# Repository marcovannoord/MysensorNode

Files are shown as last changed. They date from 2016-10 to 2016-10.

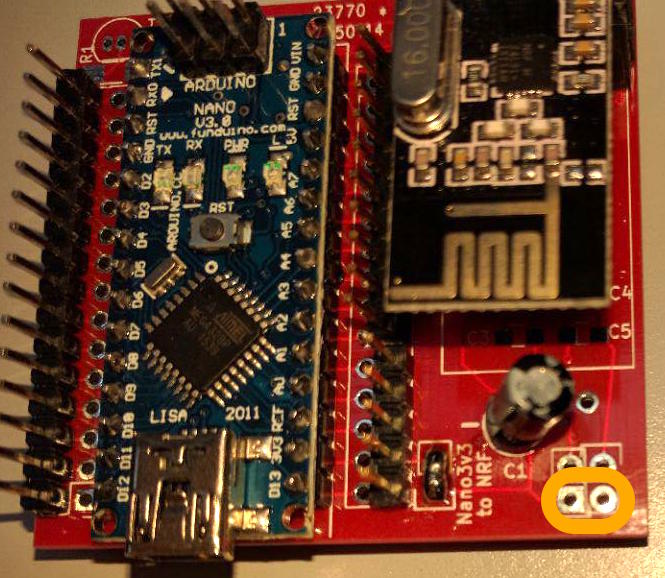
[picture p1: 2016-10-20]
how-to-use-battery-power.jpg

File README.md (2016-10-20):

# MysensorNode
A MySensor node that uses an NTF24l01+ wireless unit to connect to the gateway. We use an Arduino Nano. In this repository you'll find the files i used to design the PCB (KiCad). Unless you're planning to produce your own boards, you don't need those files. 

If you use this board, it means you've connected your Arduino Nano to your NRF24L01+. Also the pins of the Nano are broken out (at the side of the Nano), so you can easily solder wires to them or even use some fancy headers to connect your creations. 

# Why use an arduino Nano instead of the Pro mini? 
Okay, this is a tradeoff between usability and energy-consumption. The pro mini is way better in terms of size and energy-consumption - it doesn't have the usb-controller - but is a lot harder for beginners to program, and using an FTDI-cable might be a bit scary for beginning users. 

If you wanna save energy , just cut the powertraces for the usb-serial chip. If you're feeling fancy, make a header so you can reconnect the usb-serial. Or you can just program it using the ICSP header using a programmer :) 

# Getting started: getting mysensors working
After you made yourself familiar with the mySensors system https://www.mysensors.org , you figured you need a gateway and of course some nodes to which you connect sensors.

## Warning: Install the library from the MySensors.zip i attached in this repo.

1. Solder female headers on the PCB, exactly where the Arduino Nano is supposed to be and also where the NRF24L01+ should connect. This way you can always remove the nano for testing purposes.
2. Connect the two pins next to "Nano3v3 to NRF" to each other, which will supply the wireless chip with some juice.
3. solder a 47uF electrolythic condensator to C1. Make sure that the "-" of the ElCo faces the same side as the "-" on the PCB.
4. Plug in the Arduino Nano (USB connector should be slightly sticking out) and the NRF24L01+(not sticking out).
5. Plug in the USB, and upload the "SerialGateway" sketch from the MySensors arduino library (https://www.mysensors.org/build/serial_gateway). 
6. Make any of the sensors, for example https://www.mysensors.org/build/binary . 
7. Connect the serial gateway to a Controller (i advice https://www.mysensors.org/controller/mynodesnet or Domoticz) and you're ready to receive data! (p.s. there's a controller in the greenhouse @ RDM already available, connect to DoosWifi and connect to Raspberrypiarjen.local )

After powering on your wireless node, it will search for an active controller in the network, which it will ask a unique device id; it will store that internally in its EEPROM. It will be saved even after losing power. Now you can send data to the controller. Using default settings, you can send/receive approximately 200 messages per second.

# FAQ:

Q: i get an error compiling the system can't find MySensors.h

A: in your sketch, change the reference from mysensors.h to MySensor.h (so remove the "s").

# More Info:
See the Wiki <https://github.com/marcovannoord/MysensorNode/wiki>

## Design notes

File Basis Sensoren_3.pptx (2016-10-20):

## Basis Sensoren Week 3

Door: marco van Noord
Email: Nooma@hr.nl

## Vorige keer

- Digitale sensoren
  - Hoe beviel dat?Beter? Minder?
- Meer libraries, minder zelf schrijven, goed of slecht?

## Vandaag

- Arduino als Smart Thing
  - Power consumption
  - Communicatie

## Draadloze communicatie

## Draadloze communicatie

- Wi-Fi
- Xbee
- Infrarood?
- 434MHz (klik-aan-klik-uit)
- GSM/GPRS
- Lora
- Bluetooth
- …

## Beste kiezen

- Range
  - Repeaters mogelijk?
- Energieverbruik (!)
- Kosten
- Formaat
- Benodigde snelheid

## Energieverbruik

- Draadloze communicatie gebruikt “veel”
  - Vaak het duurste
- Wat als de batterijen leeg zijn?
- Wat voor energiebron (groot/klein, duur/goedkoop, speciaal/standaard, etc…)
- Gebruik niets wat je niet nodig hebt

## Gedrag batterijen

- Verder ontladen => lager voltage
- Microcontroller heeft minimum nodig (zie datasheet)
- Te weinig voltage -> rare dingen doen!
  - Beveiliging(brown-out detection)
- Hoger voltage -> meer verbruik

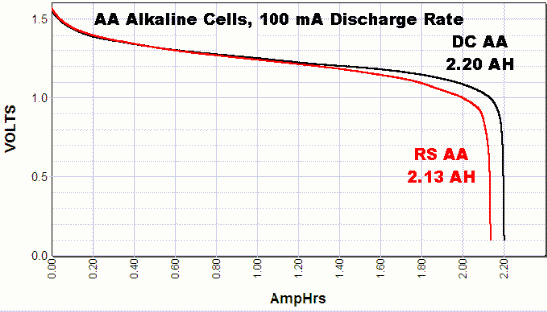
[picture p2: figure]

## Invloed energieverbruik Arduino

- Snelheid (een kloktik kost energie)
  - Dus: veel processing is duur
- Gebruik onboard devices
  - Serieel, SPI, I2C, Interne/externe klok,A/D converter, LED’s
- Voltage regelaars
- Timers
- Interrupts
- Stroom standaard Uno: 47mA

## Design for low-power environments

- Schakel uit wat je niet gebruikt
- Koppel los wat je niet gebruikt
- Debug/statusLED’s nodig in productie?
- Juiste voltage
  - Niet te hoog, niet te lag
- Kloksnelheid aanpassen
- Schakel uit wat je niet continu nodig hebt
- Houd je accuniveau in de gaten
- Slapen

## Sleep

- Sleept zorgt voor lage power-consumption
- Code stopt met draaien!
- Wakker worden: interrupt
  - Timer of extern?

## Stroomgebruik Atmega328p @16MHz

- Arduino: 47mA
- Atmega328P: 36mA
- SLEEP_MODE_IDLE: 15 mA
- SLEEP_MODE_ADC: 6.5 mA
- SLEEP_MODE_PWR_SAVE: 1.62 mA
- SLEEP_MODE_EXT_STANDBY: 1.62 mA
- SLEEP_MODE_STANDBY : 0.84 mA
- SLEEP_MODE_PWR_DOWN : 0.36 mA
- http://www.rocketscream.com/blog/2011/07/04/lightweight-low-power-arduino-library/ (http://www.rocketscream.com/blog/2011/07/04/lightweight-low-power-arduino-library/)

## Opdracht

- Maak een smart thing(sensor)
- Lichtmeter, temperatuur, beweging, vochtigheid, etc…
- Minimaal 3 maanden op 2*AA batterijen (+-2700mAh)
- Draadloos verzenden
  - Ontvanger zelf maken, geen verdere eisen aan power
- 3 weken (24 November)
- Overleg voor beschikbaarheid onderdelen met Marco
- Batterijniveau doorsturen
- Onderzoeksverslag: waarom gekozen voor welke techniek(en)
- Groepje max 4 studenten

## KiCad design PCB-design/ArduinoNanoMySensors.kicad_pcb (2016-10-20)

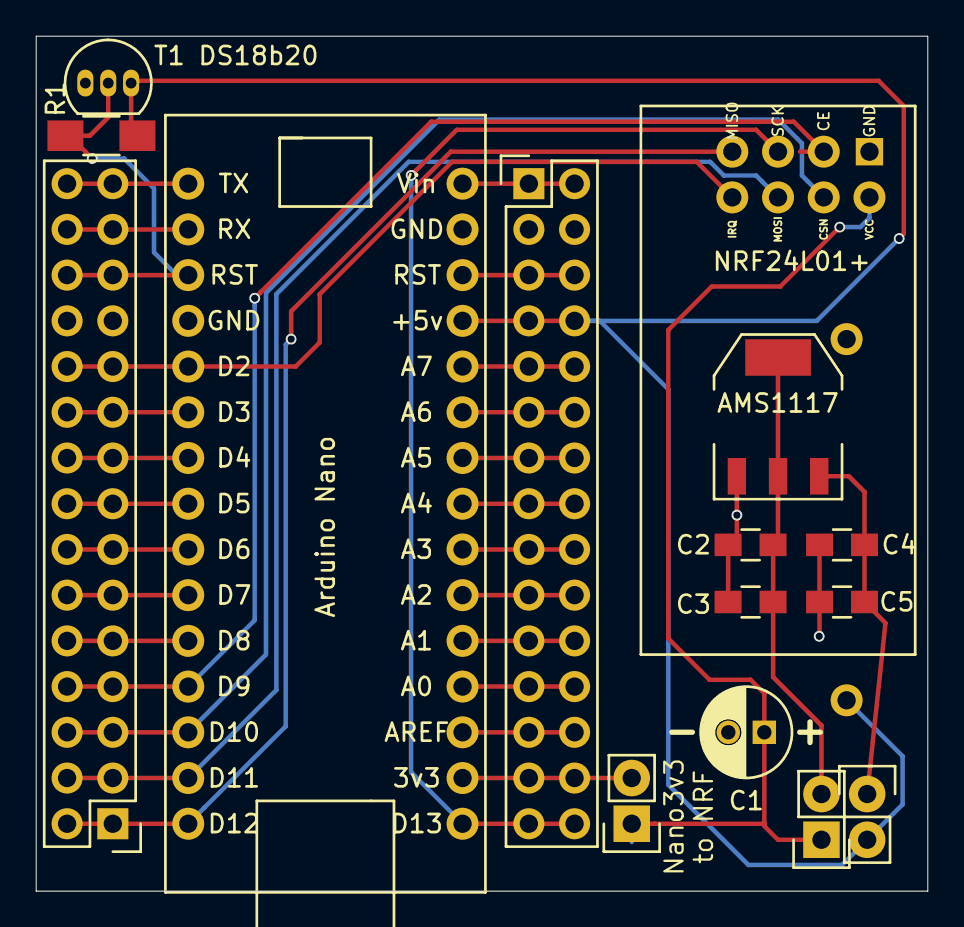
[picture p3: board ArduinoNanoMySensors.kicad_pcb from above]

Board: 2 copper layers, 49.5 x 47.5 mm, 16 parts (1 on the bottom side), 32 nets.

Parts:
AMS1117: AMS1117; SOT-223
Arduino Nano: ArduinoNano
BT1: Battery; CR3032Holder
C1: 100u; C_Radial_D5_L11_P2
C2, C5: 10u; C_0805_HandSoldering
C3, C4: 0.1u; C_0805_HandSoldering
JP1, JP2, JP3: JUMPER; Pin_Header_Straight_1x02
NRF24L01+: NRF24L01+
P1, P2: CONN_02X15; Pin_Header_Straight_2x15
R1: 4K7; R_1206_HandSoldering
T1 DS18b20: DS18B20; TO-92_Inline_Narrow_Oval

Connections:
+3V3: C1.1, JP1.1, JP3.1, NRF24L01+.8
GND: AMS1117.1, Arduino Nano.4, Arduino Nano.29, BT1.2, C1.2, C2.2, C3.2, C4.2, C5.2, NRF24L01+.1, P1.23, P1.24, P2.3, P2.4, T1 DS18b20.1
unnamed: Arduino Nano.27, BT1.1, JP2.2, P2.7, P2.8, R1.1, T1 DS18b20.3
unnamed: AMS1117.2, C2.1, C3.1, JP1.2
unnamed: AMS1117.3, C4.1, C5.1, JP2.1
unnamed: Arduino Nano.17, JP3.2, P2.27, P2.28
unnamed: Arduino Nano.15, NRF24L01+.4, P1.1, P1.2
unnamed: Arduino Nano.14, NRF24L01+.6, P1.3, P1.4
unnamed: Arduino Nano.13, NRF24L01+.7, P1.5, P1.6
unnamed: Arduino Nano.12, NRF24L01+.2, P1.7, P1.8
unnamed: Arduino Nano.11, P1.9, P1.10
unnamed: Arduino Nano.10, P1.11, P1.12
unnamed: Arduino Nano.9, P1.13, P1.14
unnamed: Arduino Nano.8, P1.15, P1.16
unnamed: Arduino Nano.7, P1.17, P1.18
unnamed: Arduino Nano.6, P1.19, P1.20
unnamed: Arduino Nano.5, NRF24L01+.5, P1.21, P1.22
unnamed: Arduino Nano.3, P1.25, P1.26, R1.2, T1 DS18b20.2
unnamed: Arduino Nano.2, P1.27, P1.28
unnamed: Arduino Nano.1, P1.29, P1.30
unnamed: Arduino Nano.30, P2.1, P2.2
unnamed: Arduino Nano.28, P2.5, P2.6
unnamed: Arduino Nano.26, P2.9, P2.10
unnamed: Arduino Nano.25, P2.11, P2.12
unnamed: Arduino Nano.24, P2.13, P2.14
unnamed: Arduino Nano.23, P2.15, P2.16
unnamed: Arduino Nano.22, P2.17, P2.18
unnamed: Arduino Nano.21, P2.19, P2.20
unnamed: Arduino Nano.20, P2.21, P2.22
unnamed: Arduino Nano.19, P2.23, P2.24
unnamed: Arduino Nano.18, P2.25, P2.26
unnamed: Arduino Nano.16, NRF24L01+.3, P2.29, P2.30

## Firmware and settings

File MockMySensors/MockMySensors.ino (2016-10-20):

/*
* MockMySensors
*
* This skecth is intended to crate fake sensors which register and respond to the controller
* ***
* Barduino 2015, GizMoCuz 2015
*/

// Enable debug prints to serial monitor
#define MY_DEBUG 

// Enable and select radio type attached
#define MY_RADIO_NRF24
//#define MY_RADIO_RFM69

#define MY_NODE_ID 254

#include <SPI.h>
#include <MySensor.h>  

#define RADIO_ERROR_LED_PIN 4  // Error led pin
#define RADIO_RX_LED_PIN    6  // Receive led pin
#define RADIO_TX_LED_PIN    5  // the PCB, on board LED

// Wait times
#define LONG_WAIT 500
#define SHORT_WAIT 50

#define SKETCH_NAME "MockMySensors "
#define SKETCH_VERSION "v0.5"

// Define Sensors ids
/*      S_DOOR, S_MOTION, S_SMOKE, S_LIGHT, S_DIMMER, S_COVER, S_TEMP, S_HUM, S_BARO, S_WIND,
	S_RAIN, S_UV, S_WEIGHT, S_POWER, S_HEATER, S_DISTANCE, S_LIGHT_LEVEL, S_ARDUINO_NODE,
	S_ARDUINO_REPEATER_NODE, S_LOCK, S_IR, S_WATER, S_AIR_QUALITY, S_CUSTOM, S_DUST,
	S_SCENE_CONTROLLER
*/

////#define ID_S_ARDUINO_NODE            //auto defined in initialization
////#define ID_S_ARDUINO_REPEATER_NODE   //auto defined in initialization 


// Some of these ID's have not been updated for v1.5.  Uncommenting too many of them
// will make the sketch too large for a pro mini's memory so it's probably best to try
// one at a time.

#define ID_S_ARMED             0  // dummy to controll armed stated for several sensors
#define ID_S_DOOR              1
//#define ID_S_MOTION            2
//#define ID_S_SMOKE             3
//#define ID_S_LIGHT             4
//#define ID_S_DIMMER            5
//#define ID_S_COVER             6
//#define ID_S_TEMP              7
//#define ID_S_HUM               8
//#define ID_S_BARO              9
//#define ID_S_WIND              10
//#define ID_S_RAIN              11
//#define ID_S_UV                12
//#define ID_S_WEIGHT            13 
//#define ID_S_POWER             14
//#define ID_S_HEATER            15
//#define ID_S_DISTANCE          16
//#define ID_S_LIGHT_LEVEL       17 
//#define ID_S_LOCK              18
//#define ID_S_IR                19
//#define ID_S_WATER             20 
//#define ID_S_AIR_QUALITY       21 
//#define ID_S_DUST              22
//#define ID_S_SCENE_CONTROLLER  23
//// Lib 1.5 sensors
//#define ID_S_RGB_LIGHT         24
//#define ID_S_RGBW_LIGHT        25
//#define ID_S_COLOR_SENSOR      26
//#define ID_S_HVAC              27
//#define ID_S_MULTIMETER        28
//#define ID_S_SPRINKLER         29
//#define ID_S_WATER_LEAK        30
//#define ID_S_SOUND             31
//#define ID_S_VIBRATION         32
//#define ID_S_MOISTURE          33
//
//#define ID_S_CUSTOM            99



// Global Vars
unsigned long SLEEP_TIME = 900000; // Sleep time between reads (in milliseconds)
boolean metric = true;
long randNumber;


//Instanciate Messages objects

#ifdef ID_S_ARMED
  bool isArmed;
#endif

#ifdef ID_S_DOOR // V_TRIPPED, V_ARMED
  MyMessage msg_S_DOOR_T(ID_S_DOOR,V_TRIPPED);
  MyMessage msg_S_DOOR_A(ID_S_DOOR,V_ARMED);
#endif

#ifdef ID_S_MOTION // V_TRIPPED, V_ARMED
  MyMessage msg_S_MOTION_A(ID_S_MOTION,V_ARMED);
  MyMessage msg_S_MOTION_T(ID_S_MOTION,V_TRIPPED);
#endif

#ifdef ID_S_SMOKE  // V_TRIPPED, V_ARMED
  MyMessage msg_S_SMOKE_T(ID_S_SMOKE,V_TRIPPED);
  MyMessage msg_S_SMOKE_A(ID_S_SMOKE,V_ARMED);
#endif

#ifdef ID_S_LIGHT
  MyMessage msg_S_LIGHT(ID_S_LIGHT,V_LIGHT);
  bool isLightOn=0;
#endif

#ifdef ID_S_DIMMER
  MyMessage msg_S_DIMMER(ID_S_DIMMER,V_DIMMER);
  int dimmerVal=100;
#endif

#ifdef ID_S_COVER
  MyMessage msg_S_COVER_U(ID_S_COVER,V_UP);
  MyMessage msg_S_COVER_D(ID_S_COVER,V_DOWN);
  MyMessage msg_S_COVER_S(ID_S_COVER,V_STOP);
  MyMessage msg_S_COVER_V(ID_S_COVER,V_VAR1);
  int coverState=0; //0=Stop; 1=up; -1=down
#endif

#ifdef ID_S_TEMP
  MyMessage msg_S_TEMP(ID_S_TEMP,V_TEMP);
#endif

#ifdef ID_S_HUM
  MyMessage msg_S_HUM(ID_S_HUM,V_HUM);
#endif

#ifdef ID_S_BARO
  MyMessage msg_S_BARO_P(ID_S_BARO,V_PRESSURE);
  MyMessage msg_S_BARO_F(ID_S_BARO,V_FORECAST);
#endif

#ifdef ID_S_WIND
  MyMessage msg_S_WIND_S(ID_S_WIND,V_WIND);
  MyMessage msg_S_WIND_G(ID_S_WIND,V_GUST);
  MyMessage msg_S_WIND_D(ID_S_WIND,V_DIRECTION);
#endif

#ifdef ID_S_RAIN
  MyMessage msg_S_RAIN_A(ID_S_RAIN,V_RAIN);
  MyMessage msg_S_RAIN_R(ID_S_RAIN,V_RAINRATE);
#endif

#ifdef ID_S_UV
  MyMessage msg_S_UV(ID_S_UV,V_UV);
#endif

#ifdef ID_S_WEIGHT
  MyMessage msg_S_WEIGHT(ID_S_WEIGHT,V_WEIGHT);
#endif

#ifdef ID_S_POWER
  MyMessage msg_S_POWER_W(ID_S_POWER,V_WATT);
  MyMessage msg_S_POWER_K(ID_S_POWER,V_KWH);
#endif


#ifdef ID_S_HEATER

  //////// REVIEW IMPLEMENTATION ////////////
  
  MyMessage msg_S_HEATER_SET_POINT(ID_S_HEATER,V_HVAC_SETPOINT_HEAT);  // HVAC/Heater setpoint (Integer between 0-100). S_HEATER, S_HVAC
  MyMessage msg_S_HEATER_FLOW_STATE(ID_S_HEATER,V_HVAC_FLOW_STATE);     // Mode of header. One of "Off", "HeatOn", "CoolOn", or "AutoChangeOver" // S_HVAC, S_HEATER
  
  //MyMessage msg_S_HEATER_STATUS(ID_S_HEATER,V_STATUS);
  //MyMessage msg_S_HEATER_TEMP(ID_S_HEATER,V_TEMP);
  
  float heater_setpoint=21.5;
  String heater_flow_state="Off";
  
//  float heater_temp=23.5;
//  bool heater_status=false;
  
  
  // V_TEMP                // Temperature
  // V_STATUS              // Binary status. 0=off 1=on
  // V_HVAC_FLOW_STATE     // Mode of header. One of "Off", "HeatOn", "CoolOn", or "AutoChangeOver"
  // V_HVAC_SPEED          // HVAC/Heater fan speed ("Min", "Normal", "Max", "Auto")
  // V_HVAC_SETPOINT_HEAT  // HVAC/Heater setpoint
#endif

#ifdef ID_S_DISTANCE
  MyMessage msg_S_DISTANCE(ID_S_DISTANCE,V_DISTANCE);
#endif

#ifdef ID_S_LIGHT_LEVEL
  MyMessage msg_S_LIGHT_LEVEL(ID_S_LIGHT_LEVEL,V_LIGHT_LEVEL);
#endif

#ifdef ID_S_LOCK
  MyMessage msg_S_LOCK(ID_S_LOCK,V_LOCK_STATUS);
  bool isLocked = 0;
#endif

#ifdef ID_S_IR
  MyMessage msg_S_IR_S(ID_S_IR,V_IR_SEND);
  MyMessage msg_S_IR_R(ID_S_IR,V_IR_RECEIVE);
  long irVal = 0;
#endif

#ifdef ID_S_WATER
  MyMessage msg_S_WATER_F(ID_S_WATER,V_FLOW);
  MyMessage msg_S_WATER_V(ID_S_WATER,V_VOLUME);
#endif

#ifdef ID_S_AIR_QUALITY
  MyMessage msg_S_AIR_QUALITY(ID_S_AIR_QUALITY,V_LEVEL);
#endif

#ifdef ID_S_DUST
  MyMessage msg_S_DUST(ID_S_DUST,V_LEVEL);
#endif

#ifdef ID_S_SCENE_CONTROLLER
  MyMessage msg_S_SCENE_CONTROLLER_ON(ID_S_SCENE_CONTROLLER,V_SCENE_ON);
  MyMessage msg_S_SCENE_CONTROLLER_OF(ID_S_SCENE_CONTROLLER,V_SCENE_OFF);
  // not sure if scene controller sends int or chars
  // betting on ints as Touch Display Scen by Hek // compiler warnings
  char *scenes[] = {
    (char *)"Good Morning", 
    (char *)"Clean Up!", 
    (char *)"All Lights Off", 
    (char *)"Music On/Off"
  };
  
  int sceneVal=0;
  int sceneValPrevious=0;
  
#endif

#ifdef ID_S_RGB_LIGHT 
  MyMessage msg_S_RGB_LIGHT_V_RGB(ID_S_RGB_LIGHT,V_RGB);
  MyMessage msg_S_RGB_LIGHT_V_WATT(ID_S_RGB_LIGHT,V_WATT);
  String rgbState="000000";
  //RGB light V_RGB, V_WATT 
  //RGB value transmitted as ASCII hex string (I.e "ff0000" for red)
#endif

#ifdef ID_S_RGBW_LIGHT
  MyMessage msg_S_RGBW_LIGHT_V_RGBW(ID_S_RGBW_LIGHT,V_RGBW);
  MyMessage msg_S_RGBW_LIGHT_V_WATT(ID_S_RGBW_LIGHT,V_WATT);
  String rgbwState="00000000";
  //RGBW light (with separate white component)	V_RGBW, V_WATT
  //RGBW value transmitted as ASCII hex string (I.e "ff0000ff" for red + full white)	S_RGBW_LIGHT
#endif

#ifdef ID_S_COLOR_SENSOR
  MyMessage msg_S_COLOR_SENSOR_V_RGB(ID_S_COLOR_SENSOR,V_RGB);
  //Color sensor	V_RGB
  //RGB value transmitted as ASCII hex string (I.e "ff0000" for red)	S_RGB_LIGHT, S_COLOR_SENSOR
#endif

#ifdef ID_S_HVAC
  MyMessage msg_S_HVAC_V_HVAC_SETPOINT_HEAT(ID_S_HVAC,V_HVAC_SETPOINT_HEAT);
  MyMessage msg_S_HVAC_V_HVAC_SETPOINT_COOL(ID_S_HVAC,V_HVAC_SETPOINT_COOL);
  MyMessage msg_S_HVAC_V_HVAC_FLOW_STATET(ID_S_HVAC,V_HVAC_FLOW_STATE);
  MyMessage msg_S_HVAC_V_HVAC_FLOW_MODE(ID_S_HVAC,V_HVAC_FLOW_MODE);
  MyMessage msg_S_HVAC_V_HVAC_SPEED(ID_S_HVAC,V_HVAC_SPEED);
  
  float hvac_SetPointHeat = 16.5;
  float hvac_SetPointCool = 25.5;
  String hvac_FlowState   = "AutoChangeOver";
  String hvac_FlowMode    = "Auto";
  String hvac_Speed       = "Normal";

  //Thermostat/HVAC device	
  //V_HVAC_SETPOINT_HEAT,  // HVAC/Heater setpoint
  //V_HVAC_SETPOINT_COOL,  // HVAC cold setpoint
  //V_HVAC_FLOW_STATE,     // Mode of header. One of "Off", "HeatOn", "CoolOn", or "AutoChangeOver"
  //V_HVAC_FLOW_MODE,      // Flow mode for HVAC ("Auto", "ContinuousOn", "PeriodicOn")
  //V_HVAC_SPEED           // HVAC/Heater fan speed ("Min", "Normal", "Max", "Auto")
  
  // NOT IMPLEMENTED YET
  //V_TEMP                 // Temperature
  //V_STATUS               // Binary status. 0=off 1=on
#endif

#ifdef ID_S_MULTIMETER
  MyMessage msg_S_MULTIMETER_V_IMPEDANCE(ID_S_MULTIMETER,V_IMPEDANCE);
  MyMessage msg_S_MULTIMETER_V_VOLTAGE(ID_S_MULTIMETER,V_VOLTAGE);
  MyMessage msg_S_MULTIMETER_V_CURRENT(ID_S_MULTIMETER,V_CURRENT);

  // Multimeter device	V_VOLTAGE, V_CURRENT, V_IMPEDANCE
  // V_IMPEDANCE	14	Impedance value
  // V_VOLTAGE	38	Voltage level
  // V_CURRENT	39	Current level
#endif

#ifdef ID_S_SPRINKLER
  // S_SPRINKLER	31	Sprinkler device	V_STATUS (turn on/off), V_TRIPPED (if fire detecting device)
  // V_STATUS	2	Binary status. 0=off 1=on	
  // V_ARMED	15	Armed status of a security sensor. 1=Armed, 0=Bypassed
  // V_TRIPPED	16	Tripped status of a security sensor. 1=Tripped, 0=Untripped
#endif

#ifdef ID_S_WATER_LEAK
#endif
#ifdef ID_S_SOUND
#endif
#ifdef ID_S_VIBRATION
#endif
#ifdef ID_S_MOISTURE
#endif

#ifdef ID_S_MOISTURE
  MyMessage msg_S_MOISTURE(ID_S_MOISTURE,V_LEVEL);
#endif 

#ifdef ID_S_CUSTOM
  MyMessage msg_S_CUSTOM_1(ID_S_CUSTOM,V_VAR1);
  MyMessage msg_S_CUSTOM_2(ID_S_CUSTOM,V_VAR2);
  MyMessage msg_S_CUSTOM_3(ID_S_CUSTOM,V_VAR3);
  MyMessage msg_S_CUSTOM_4(ID_S_CUSTOM,V_VAR4);
  MyMessage msg_S_CUSTOM_5(ID_S_CUSTOM,V_VAR5);
#endif




void setup()  
{ 
  // Random SEED
  randomSeed(analogRead(0));
  
  wait(LONG_WAIT);
  Serial.println("GW Started");
}

void presentation()  {
  // Send the Sketch Version Information to the Gateway
  Serial.print("Send Sketch Info: ");
  sendSketchInfo(SKETCH_NAME, SKETCH_VERSION);
  Serial.print(SKETCH_NAME);
  Serial.println(SKETCH_VERSION);
  wait(LONG_WAIT);
  
  // Get controller configuration
  Serial.print("Get Config: ");
  metric = getConfig().isMetric;
  Serial.println(metric ? "Metric":"Imperial");
  wait(LONG_WAIT);
  
  // Init Armed
  #ifdef ID_S_ARMED
    isArmed = true;
  #endif
    
  // Register all sensors to gw (they will be created as child devices)
  Serial.println("Presenting Nodes");
  Serial.println("________________");
  
  #ifdef ID_S_DOOR
    Serial.println("  S_DOOR");
    present(ID_S_DOOR,S_DOOR,"Outside Door");
    wait(SHORT_WAIT);
  #endif
  
  #ifdef ID_S_MOTION
    Serial.println("  S_MOTION");
    present(ID_S_MOTION,S_MOTION,"Outside Motion");
    wait(SHORT_WAIT);
  #endif
  
  #ifdef ID_S_SMOKE
    Serial.println("  S_SMOKE");
    present(ID_S_SMOKE,S_SMOKE,"Kitchen Smoke");
    wait(SHORT_WAIT);
  #endif
  
  #ifdef ID_S_LIGHT
    Serial.println("  S_LIGHT");
    present(ID_S_LIGHT,S_LIGHT,"Hall Light");
    wait(SHORT_WAIT);
  #endif
  
  #ifdef ID_S_DIMMER
    Serial.println("  S_DIMMER");
    present(ID_S_DIMMER,S_DIMMER,"Living room dimmer");
    wait(SHORT_WAIT);
  #endif
  
  #ifdef ID_S_COVER
    Serial.println("  S_COVER");
    present(ID_S_COVER,S_COVER,"Window cover");
    wait(SHORT_WAIT);
  #endif
  
  #ifdef ID_S_TEMP
    Serial.println("  S_TEMP");
    present(ID_S_TEMP,S_TEMP,"House Temperarue");
    wait(SHORT_WAIT);
  #endif
  
  #ifdef ID_S_HUM
    Serial.println("  S_HUM");
    present(ID_S_HUM,S_HUM,"Current Humidity");
    wait(SHORT_WAIT);
  #endif
  
  #ifdef ID_S_BARO
    Serial.println("  S_BARO");
    present(ID_S_BARO,S_BARO," Air pressure");
    wait(SHORT_WAIT);
  #endif
  
  #ifdef ID_S_WIND
    Serial.println("  S_WIND");
    present(ID_S_WIND,S_WIND,"Wind Station");
    wait(SHORT_WAIT);
  #endif
  
  #ifdef ID_S_RAIN
    Serial.println("  S_RAIN");
    present(ID_S_RAIN,S_RAIN,"Rain Station");
    wait(SHORT_WAIT);
  #endif
  
  #ifdef ID_S_UV
    Serial.println("  S_UV");
    present(ID_S_UV,S_UV,"Ultra Violet");
    wait(SHORT_WAIT);
  #endif
  
  #ifdef ID_S_WEIGHT
    Serial.println("  S_WEIGHT");
    present(ID_S_WEIGHT,S_WEIGHT,"Outdoor Scale");
    wait(SHORT_WAIT);
  #endif
  
  #ifdef ID_S_POWER
    Serial.println("  S_POWER");
    present(ID_S_POWER,S_POWER,"Power Metric");
    wait(SHORT_WAIT);
  #endif
  
  #ifdef ID_S_HEATER
    Serial.println("  S_HEATER");
    present(ID_S_HEATER,S_HEATER,"Garage Heater");
    wait(SHORT_WAIT);
  #endif
  
  #ifdef ID_S_DISTANCE
    Serial.println("  S_DISTANCE");
    present(ID_S_DISTANCE,S_DISTANCE,"Distance Measure");
    wait(SHORT_WAIT);
  #endif
  
  #ifdef ID_S_LIGHT_LEVEL
    Serial.println("  S_LIGHT_LEVEL");
    present(ID_S_LIGHT_LEVEL,S_LIGHT_LEVEL,"Outside Light Level");
    wait(SHORT_WAIT);
  #endif
  
  #ifdef ID_S_LOCK
    Serial.println("  S_LOCK");
    present(ID_S_LOCK,S_LOCK,"Front Door Lock");
    wait(SHORT_WAIT);
  #endif
  
  #ifdef ID_S_IR
    Serial.println("  S_IR");
    present(ID_S_IR,S_IR,"Univeral Command");
    wait(SHORT_WAIT);
  #endif
  
  #ifdef ID_S_WATER
    Serial.println("  S_WATER");
    present(ID_S_WATER,S_WATER,"Water Level");
    wait(SHORT_WAIT);
  #endif
  
  #ifdef ID_S_AIR_QUALITY
    Serial.println("  S_AIR_QUALITY");
    present(ID_S_AIR_QUALITY,S_AIR_QUALITY,"Air Station");
    wait(SHORT_WAIT);
  #endif
  
  #ifdef ID_S_DUST  
    Serial.println("  S_DUST");
    present(ID_S_DUST,S_DUST,"Dust Level");
    wait(SHORT_WAIT);
  #endif
  
  #ifdef ID_S_SCENE_CONTROLLER
    Serial.println("  S_SCENE_CONTROLLER");
    present(ID_S_SCENE_CONTROLLER,S_SCENE_CONTROLLER,"Scene Controller");
    wait(SHORT_WAIT);
  #endif
  
  #ifdef ID_S_RGB_LIGHT
    Serial.println("  RGB_LIGHT");
    present(ID_S_RGB_LIGHT,S_RGB_LIGHT,"Mood Light");
    wait(SHORT_WAIT);
  #endif
  
  #ifdef ID_S_RGBW_LIGHT
    Serial.println("  RGBW_LIGHT");
    present(ID_S_RGBW_LIGHT,S_RGBW_LIGHT,"Mood Light 2");
    wait(SHORT_WAIT);
  #endif
  
  #ifdef ID_S_COLOR_SENSOR
    Serial.println("  COLOR_SENSOR");
    present(ID_S_COLOR_SENSOR,S_COLOR_SENSOR,"Hall Painting");
    wait(SHORT_WAIT);
  #endif
  
  #ifdef ID_S_HVAC
    Serial.println("  HVAC");
    present(ID_S_HVAC,S_HVAC,"HVAC");
    wait(SHORT_WAIT);
  #endif
  
  #ifdef ID_S_MULTIMETER
    Serial.println("  MULTIMETER");
    present(ID_S_MULTIMETER,S_MULTIMETER,"Electric Staion");
    wait(SHORT_WAIT);
  #endif
  
  #ifdef ID_S_SPRINKLER
  #endif
  #ifdef ID_S_WATER_LEAK
  #endif
  #ifdef ID_S_SOUND
  #endif
  #ifdef ID_S_VIBRATION
  #endif
  #ifdef ID_S_MOISTURE
  #endif

  #ifdef ID_S_MOISTURE
    Serial.println("  S_MOISTURE");
    present(ID_S_MOISTURE,S_MOISTURE,"Basement Sensor");
    wait(SHORT_WAIT);
  #endif
  
  #ifdef ID_S_CUSTOM
    Serial.println("  S_CUSTOM");
    present(ID_S_CUSTOM,S_CUSTOM,"Other Stuff");
    wait(SHORT_WAIT);
  #endif



Serial.println("________________");

}

void loop()      
{ 
  Serial.println("");
  Serial.println("");
  Serial.println("");
  Serial.println("#########################"); 
  randNumber=random(0,101);
  
  Serial.print("RandomNumber:");
  Serial.println(randNumber);
  // Send fake battery level
  Serial.println("Send Battery Level");
  sendBatteryLevel(randNumber);
  wait(LONG_WAIT);
  
  // Request time
  Serial.println("Request Time");
  requestTime();
  wait(LONG_WAIT);
  
  //Read Sensors
  #ifdef ID_S_DOOR 
    door(); 
  #endif
  
  #ifdef ID_S_MOTION
    motion();
  #endif
  
  #ifdef ID_S_SMOKE
    smoke();
  #endif
  
  #ifdef ID_S_LIGHT
    light();
  #endif
  
  #ifdef ID_S_DIMMER
    dimmer();
  #endif
  
  #ifdef ID_S_COVER
    cover();
  #endif
  
  #ifdef ID_S_TEMP
    temp();
  #endif
  
  #ifdef ID_S_HUM
    hum();
  #endif
  
  #ifdef ID_S_BARO
    baro();
  #endif
  
  #ifdef ID_S_WIND
    wind();
  #endif
  
  #ifdef ID_S_RAIN
    rain();
  #endif
  
  #ifdef ID_S_UV
    uv();
  #endif
   
  #ifdef ID_S_WEIGHT
    weight();
  #endif
  
  #ifdef ID_S_POWER
    power();
  #endif
  
  #ifdef ID_S_HEATER
    heater();
  #endif
  
  #ifdef ID_S_DISTANCE
    distance();
  #endif
  
  #ifdef ID_S_LIGHT_LEVEL
    light_level();
  #endif
  
  #ifdef ID_S_LOCK
    lock();
  #endif
  
  #ifdef ID_S_IR
    ir();
  #endif
  
  #ifdef ID_S_WATER
    water();
  #endif
  
  #ifdef ID_S_AIR_QUALITY
    air();
  #endif
  
  #ifdef ID_S_DUST
    dust();
  #endif
  
  #ifdef ID_S_SCENE_CONTROLLER
    scene();
  #endif
  
  #ifdef ID_S_RGB_LIGHT
    rgbLight();
  #endif
  
  #ifdef ID_S_RGBW_LIGHT
    rgbwLight();
  #endif
  
  #ifdef ID_S_COLOR_SENSOR
    color();
  #endif
  
  #ifdef ID_S_HVAC
    hvac();
  #endif
  
  #ifdef ID_S_MULTIMETER
    multimeter();
  #endif
  
  #ifdef ID_S_SPRINKLER
  #endif
  #ifdef ID_S_WATER_LEAK
  #endif
  #ifdef ID_S_SOUND
  #endif
  #ifdef ID_S_VIBRATION
  #endif
  #ifdef ID_S_MOISTURE
  #endif
  
  #ifdef ID_S_MOISTURE
    moisture();
  #endif   
  
  #ifdef ID_S_CUSTOM
    custom();
  #endif
  
  sendBatteryLevel(randNumber);
  wait(SHORT_WAIT);
  Serial.println("#########################");
  wait(SLEEP_TIME); //sleep a bit
}

// This is called when a new time value was received
void receiveTime(unsigned long controllerTime) {

  Serial.print("Time value received: ");
  Serial.println(controllerTime);

}

//void door(){}

#ifdef ID_S_DOOR
void door(){
 
  Serial.print("Door is: " );
  
  if (randNumber <= 50) {
    Serial.println("Open");
    send(msg_S_DOOR_T.set(1));
  } else {
    Serial.println("Closed");
    send(msg_S_DOOR_T.set(0));
  }
  #ifdef ID_S_ARMED
    Serial.print("System is: " );
    Serial.println((isArmed ? "Armed":"Disarmed"));
    send(msg_S_DOOR_A.set(isArmed));
  #endif
}
#endif

#ifdef ID_S_MOTION
void motion(){
  
  Serial.print("Motion is: " );
  
  if (randNumber <= 50) {
    Serial.println("Active");
    send(msg_S_MOTION_T.set(1));
  } else {
    Serial.println("Quiet");
    send(msg_S_MOTION_T.set(0));
  }
  
  #ifdef ID_S_ARMED
    Serial.print("System is: " );
    Serial.println((isArmed ? "Armed":"Disarmed"));
    send(msg_S_MOTION_A.set(isArmed));
  #endif
}
#endif

#ifdef ID_S_SMOKE
void smoke(){

  Serial.print("Smoke is: " );
  
  if (randNumber <= 50) {
    Serial.println("Active");
    send(msg_S_SMOKE_T.set(1));
  } else {
    Serial.println("Quiet");
    send(msg_S_SMOKE_T.set(0));
  }
  
  #ifdef ID_S_ARMED
    Serial.print("System is: " );
    Serial.println((isArmed ? "Armed":"Disarmed"));
    send(msg_S_SMOKE_A.set(isArmed));
  #endif
  
}
#endif

#ifdef ID_S_LIGHT
void light(){

  Serial.print("Light is: " );
  Serial.println((isLightOn ? "On":"Off"));
  
  send(msg_S_LIGHT.set(isLightOn));

}
#endif

#ifdef ID_S_DIMMER
void dimmer(){

  Serial.print("Dimmer is set to: " );
  Serial.println(dimmerVal);
  
  send(msg_S_DIMMER.set(dimmerVal));

}
#endif

#ifdef ID_S_COVER
void cover(){

  Serial.print("Cover is : " );

  if (coverState == 1){
      Serial.println("Opening");
      send(msg_S_COVER_U.set(1));
  }else if (coverState == -1){
      Serial.println("Closing");
      send(msg_S_COVER_D.set(0));
  }else{
      Serial.println("Idle");
      send(msg_S_COVER_S.set(-1));
  }
  send(msg_S_COVER_V.set(coverState));
}
#endif

#ifdef ID_S_TEMP
void temp(){
  
  Serial.print("Temperature is: " );
  Serial.println(map(randNumber,1,100,0,45));
  
  send(msg_S_TEMP.set(map(randNumber,1,100,0,45)));
  
}
#endif

#ifdef ID_S_HUM
void hum(){
  
  Serial.print("Humitidty is: " );
  Serial.println(randNumber);
  
  send(msg_S_HUM.set(randNumber));
  
}
#endif

#ifdef ID_S_BARO
void baro(){
  
  const char *weather[] = {"stable","sunny","cloudy","unstable","thunderstorm","unknown"};
  long pressure = map(randNumber,1,100,870,1086);// hPa?
  int forecast = map(randNumber,1,100,0,5);
  
  Serial.print("Atmosferic Pressure is: " );
  Serial.println(pressure);
  send(msg_S_BARO_P.set(pressure));
  
  Serial.print("Weather forecast: " );
  Serial.println(weather[forecast]);
  send(msg_S_BARO_F.set(weather[forecast]));
 
}
#endif

#ifdef ID_S_WIND
void wind(){
  
  Serial.print("Wind Speed is: " );
  Serial.println(randNumber);
  send(msg_S_WIND_S.set(randNumber));
  
  Serial.print("Wind Gust is: " );
  Serial.println(randNumber+10);
  send(msg_S_WIND_G.set(randNumber+10));
  
  Serial.print("Wind Direction is: " );
  Serial.println(map(randNumber,1,100,0,360));
  send(msg_S_WIND_D.set(map(randNumber,1,100,0,360)));
  
}
#endif

#ifdef ID_S_RAIN
void rain(){
  
  Serial.print("Rain ammount  is: " );
  Serial.println(randNumber);
  
  send(msg_S_RAIN_A.set(randNumber));
  
  Serial.print("Rain rate  is: " );
  Serial.println(randNumber/60);
  
  send(msg_S_RAIN_R.set(randNumber/60,1));

}
#endif

#ifdef ID_S_UV
void uv(){
  
  Serial.print("Ultra Violet level is: " );
  Serial.println(map(randNumber,1,100,0,15));
  
  send(msg_S_UV.set(map(randNumber,1,100,0,15)));

}
#endif

#ifdef ID_S_WEIGHT
void weight(){
  
  Serial.print("Weight is: " );
  Serial.println(map(randNumber,1,100,0,150));
  
  send(msg_S_WEIGHT.set(map(randNumber,1,100,0,150)));

}
#endif

#ifdef ID_S_POWER
void power(){
  
  Serial.print("Watt is: " );
  Serial.println(map(randNumber,1,100,0,150));  
  send(msg_S_POWER_W.set(map(randNumber,1,100,0,150)));

  Serial.print("KWH is: " );
  Serial.println(map(randNumber,1,100,0,150));  
  send(msg_S_POWER_K.set(map(randNumber,1,100,0,150)));

}
#endif

#ifdef ID_S_HEATER
void heater(){
//  float heater_setpoint=21.5;
//  float heater_temp=23.5;
//  bool heater_status=false;
//  String heatState="Off";
  
  Serial.print("Heater flow state is: " );
  Serial.println(heater_flow_state);
  send(msg_S_HEATER_FLOW_STATE.set(heater_flow_state.c_str()));

//  Serial.print("Heater on/off is: " );
//  Serial.println((heater_status==true)?"On":"Off");
//  send(msg_S_HEATER_STATUS.set(heater_status));
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

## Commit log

2016-07-23 Moving everything to Git, everything is now open-source
    [ArduinoNanoMySensors.kicad_pcb, ArduinoNanoMySensors.sch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]
2016-07-23 Made v0.2 with the following changes:
    - plus en min op batterij x
    -batterijpins dikker x
    -nanopins dikker x
    -nrf pins dikker x
    -polariteit duidelijk bij C1x
    - naamgeving componenten x
    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
    [ArduinoNanoMySensors.kicad_pcb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]
2016-10-12 updated hole sizes
2016-10-12 Added powerpoint sheets and an image how to connect battery power
2016-10-12 Did some cleaning up
    [ArduinoNanoMySensors.kicad_pcb, ArduinoNanoMySensors.sch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]
2016-10-20 small bug in NRF mask
    [ArduinoNanoMySensors.kicad_pcb]
